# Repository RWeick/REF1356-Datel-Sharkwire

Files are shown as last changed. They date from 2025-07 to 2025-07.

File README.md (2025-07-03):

# REF1356-Datel-Sharkwire
Everything necessary to produce the N64 Sharkwire by Datel

This repository is the culmination of a joint effort between myself, [Jhynjhiruu](https://github.com/Jhynjhiruu), and [PPCASM](https://github.com/ppcasm). Without all of us, this wouldn't be here today. Shoutout to @WISE for being a great cheerleader throughout this endeavor. This PCB has been fully evaluated and is a complete replica of the original.

This repository now enables anyone with the necessary pcb assembly skills to fabricate an N64 Sharkwire. Some components must be harvested from an N64 Gameshark or Gameshark Pro. You are on your own to acquire the modem chipset, U11, and U13. They are COTS ICs, but seemingly hard to find. If you can find datasheets for U11 and U13, please share them with us!

Happy making!

PCB Thickness: 1.2 mm

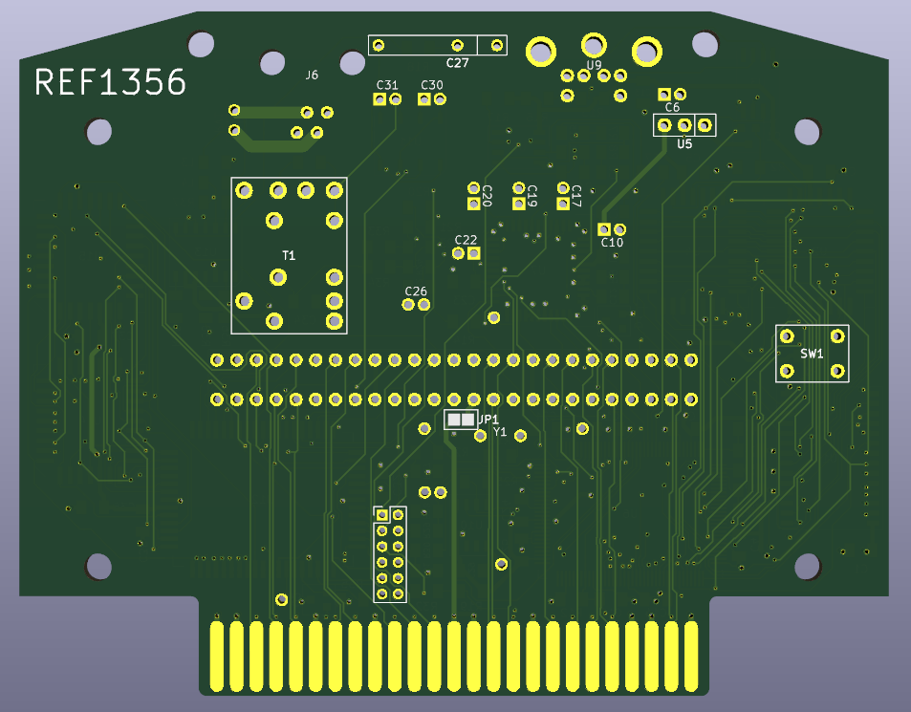
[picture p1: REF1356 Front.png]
Front side of the PCB


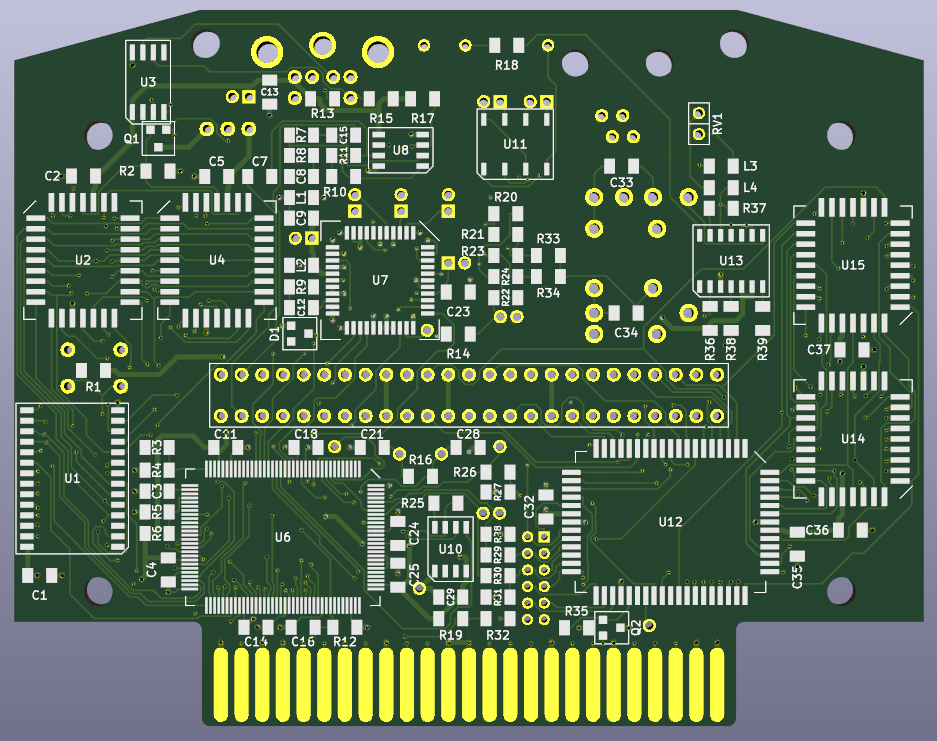
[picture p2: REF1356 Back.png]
Back side of the PCB


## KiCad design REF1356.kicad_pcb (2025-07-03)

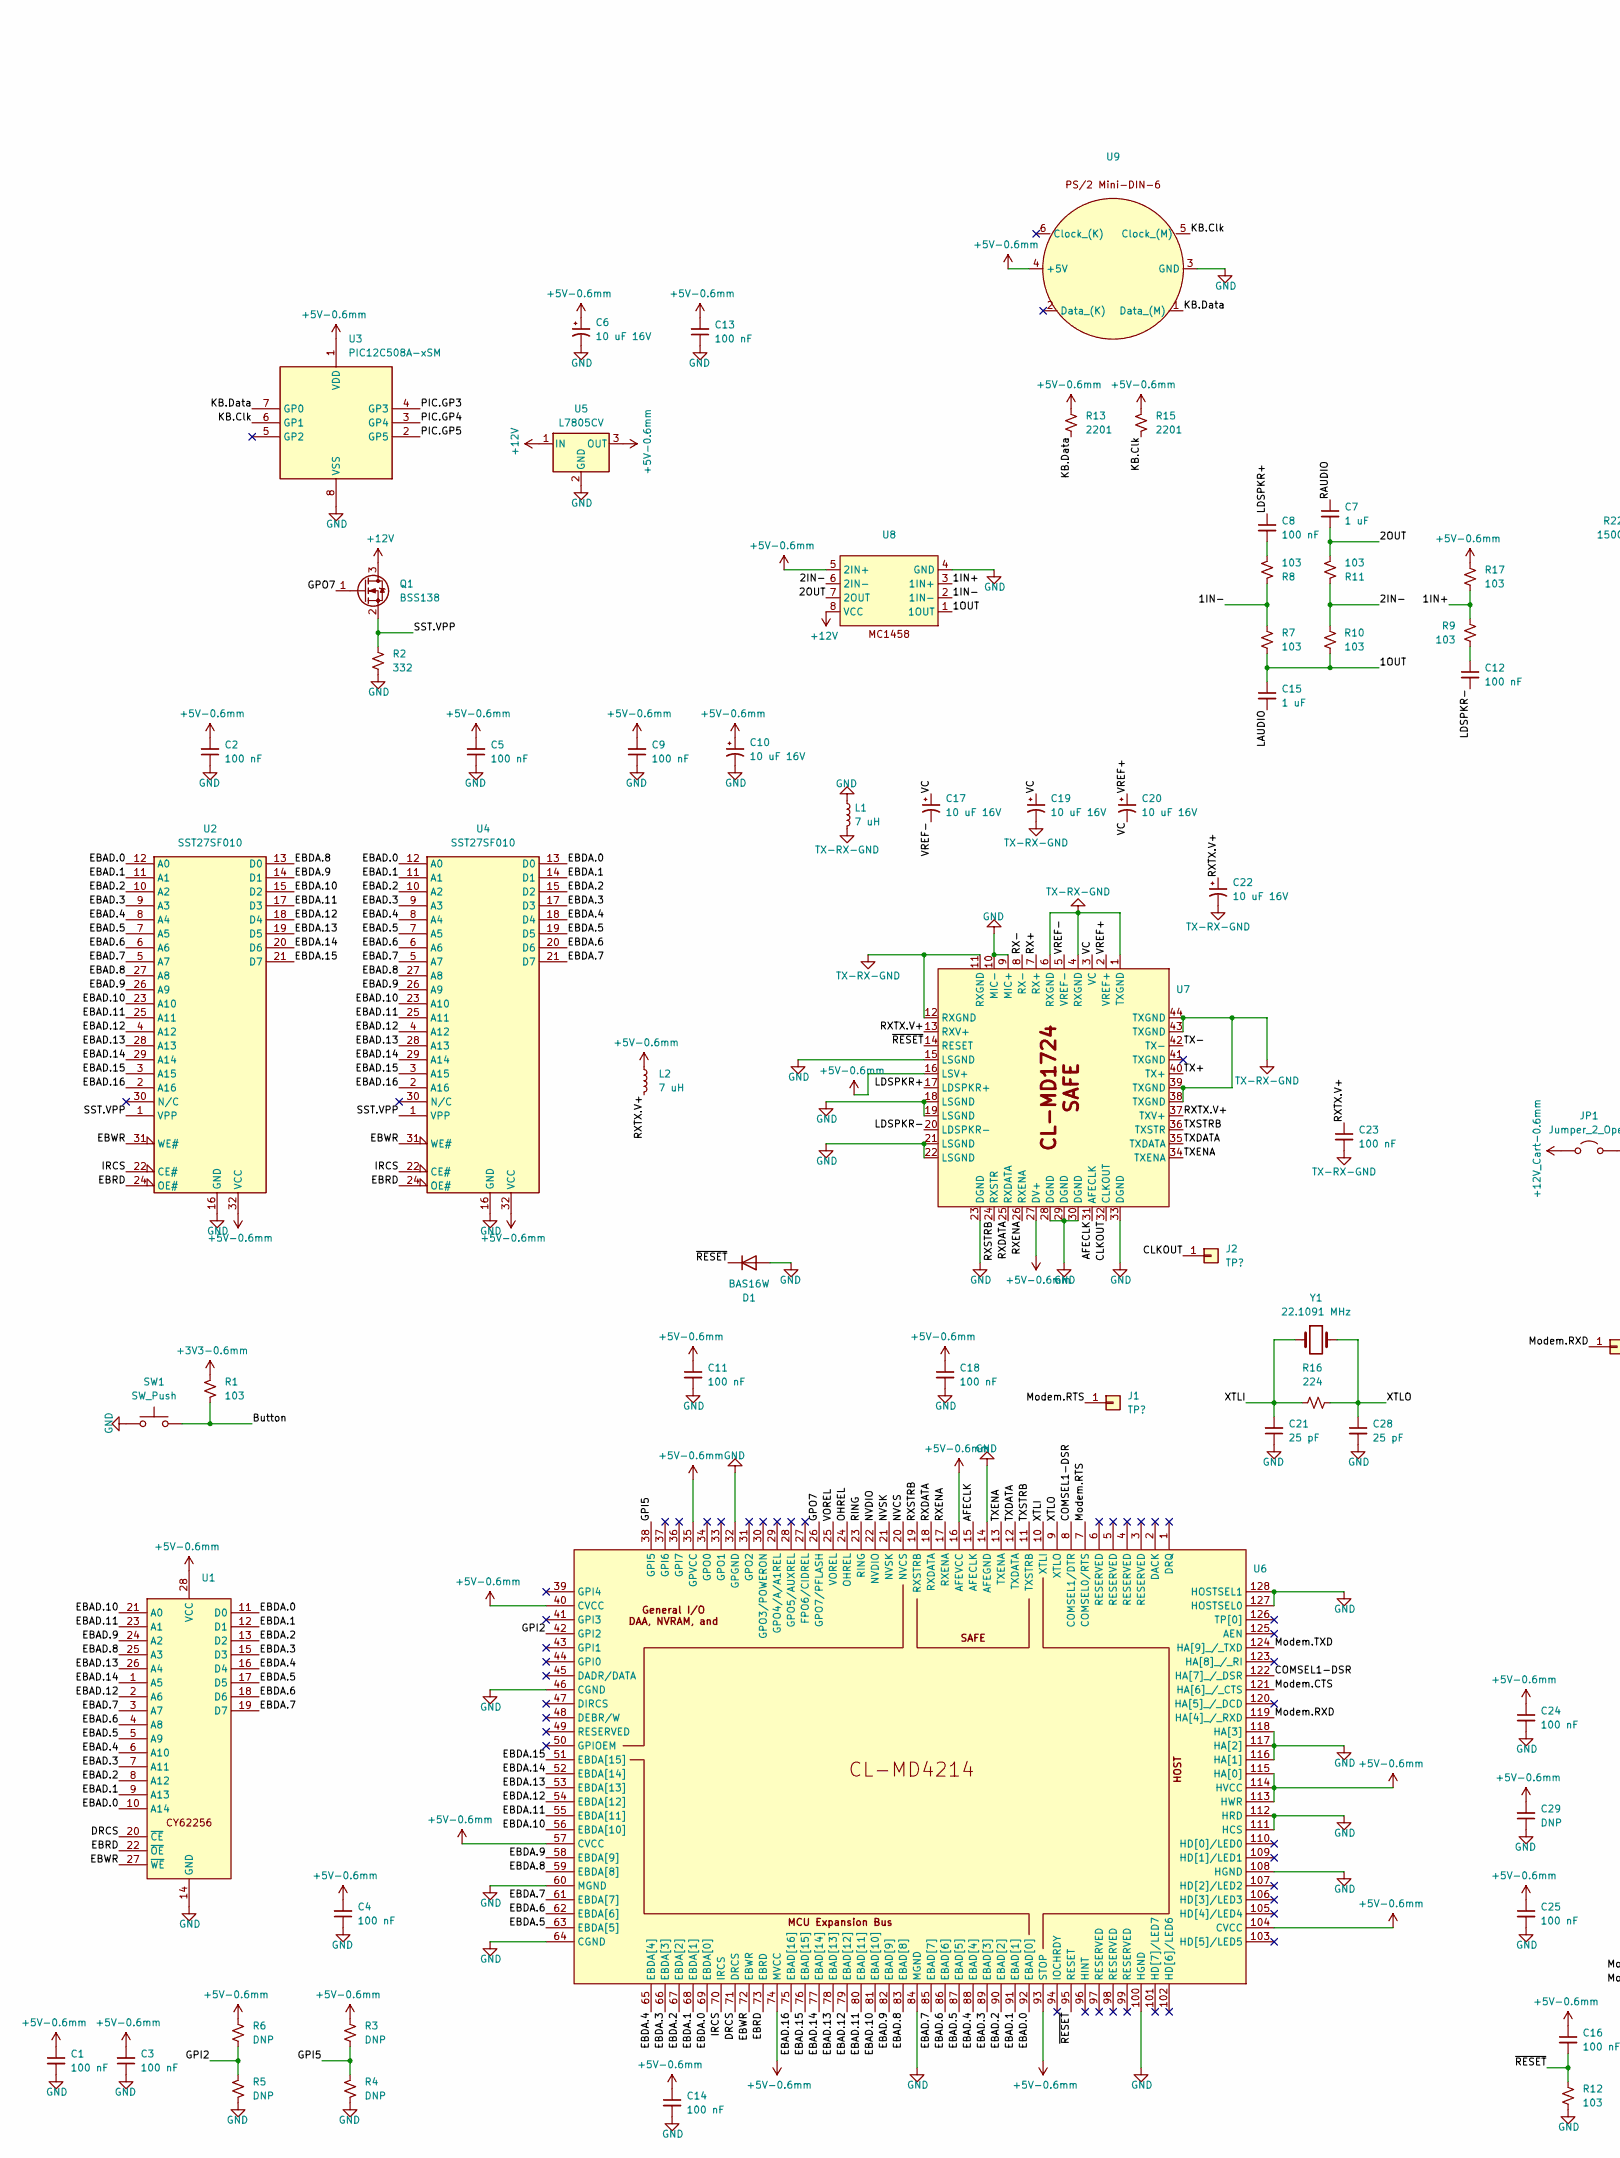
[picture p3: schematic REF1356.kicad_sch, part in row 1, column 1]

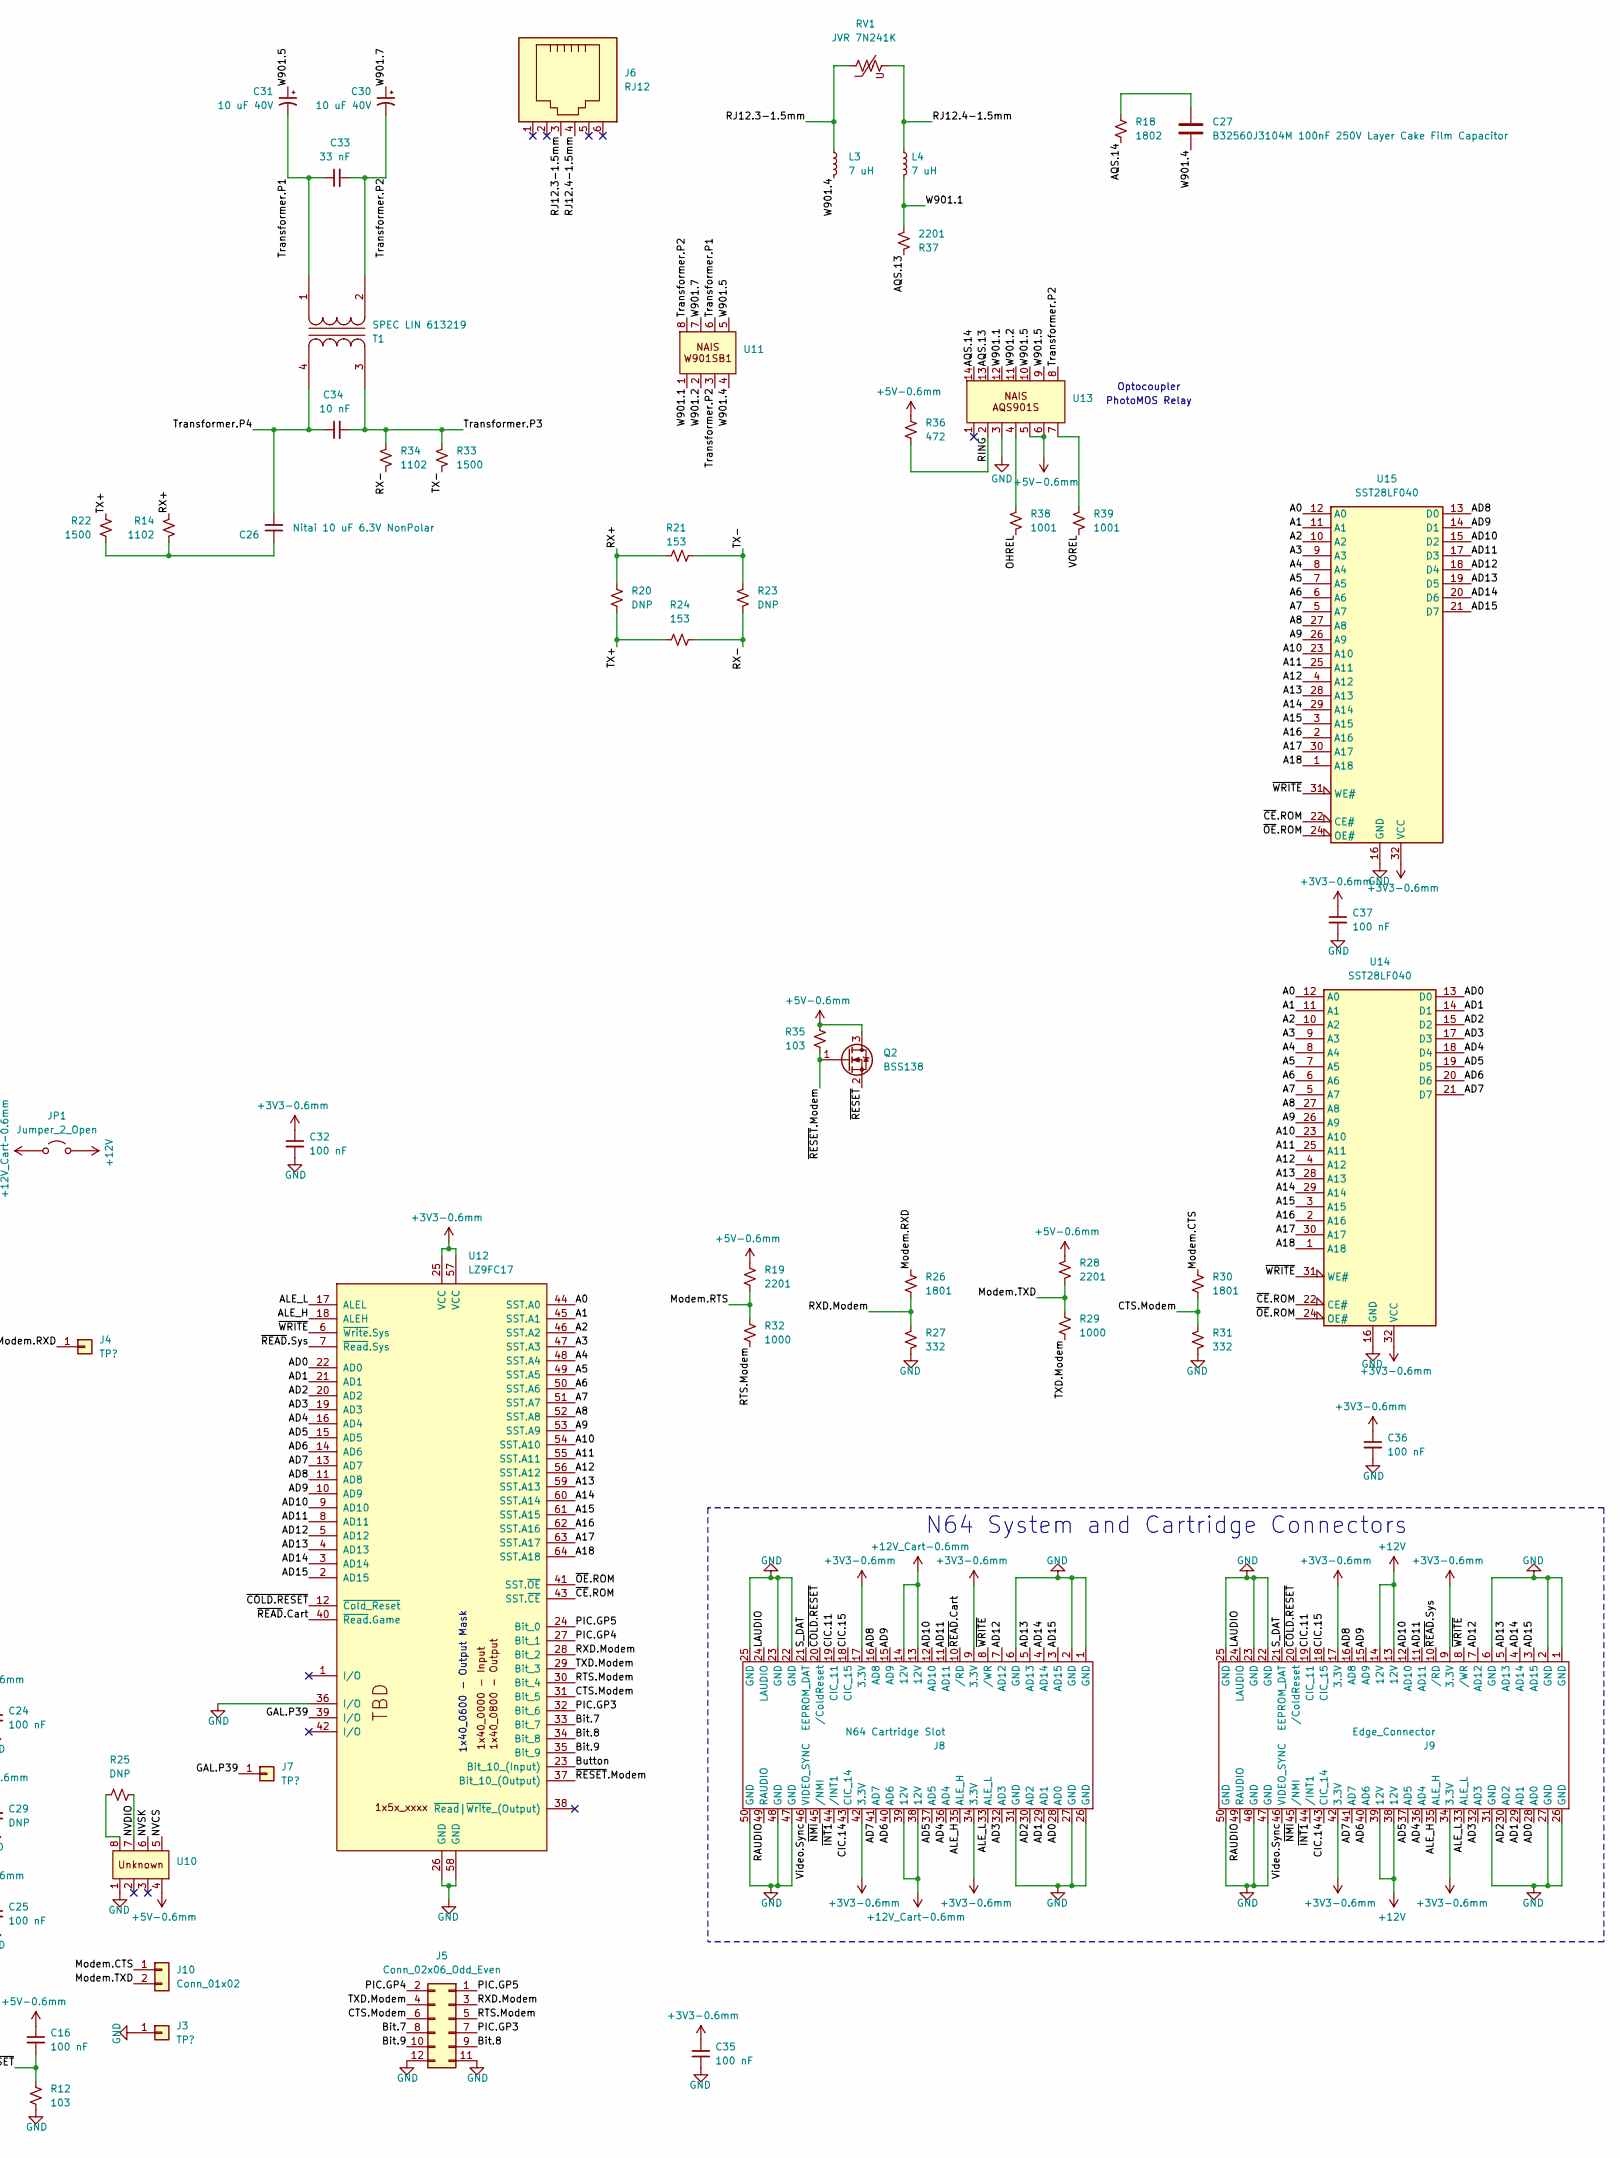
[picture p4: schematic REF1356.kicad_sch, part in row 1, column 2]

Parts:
C1, C2, C3, C4, C5, C8, C9, C11, C12, C13, C14, C16, C18, C23, C24, C25, C32, C35, C36, C37: 100 nF; SMD
C6, C10, C17, C19, C20, C22: 10 uF 16V; Polar Electrolytic
C7, C15: 1 uF; SMD
C21, C28: 25 pF; SMD
C26: Nitai 10 uF 6.3V NonPolar; Nonpolar Cap
C27: B32560J3104M 100nF 250V Layer Cake Film Capacitor; Layer Cake Film Cap
C29: DNP; SMD
C30, C31: 10 uF 40V; Polar Electrolytic
C33: 33 nF; SMD
C34: 10 nF; SMD
D1: BAS16W; Transistor
J1, J2, J3, J4, J7: TP?; Test Point
J5: Conn_02x06_Odd_Even; PinHeader_2x06_P2.00mm_Vertical
J6: RJ12; Modem Jack
J8: N64 Cartridge Slot; Cartridge Slot
J9: Edge_Connector; Edge Connector
J10: Conn_01x02; Nonpolar Cap
JP1: Jumper_2_Open; 12V Jumper
L1, L2, L3, L4: 7 uH; SMD
Q1, Q2: BSS138; Transistor
R1, R7, R8, R9, R10, R11, R12, R17, R35: 103; SMD
R2, R27, R31: 332; SMD
R3, R4, R5, R6, R20, R23, R25: DNP; SMD
R13, R15, R19, R28, R37: 2201; SMD
R14, R34: 1102; SMD
R16: 224; SMD
R18: 1802; SMD
R21, R24: 153; SMD
R22, R33: 1500; SMD
R26, R30: 1801; SMD
R29, R32: 1000; SMD
R36: 472; SMD
R38, R39: 1001; SMD
RV1: JVR 7N241K; Varistor
SW1: SW_Push; Button
T1: SPEC LIN 613219
U1: CY62256-70SNC
U2, U4: SST27SF010; PLCC32
U3: PIC12C508A-xSM; PIC 12C508A
U5: L7805CV
U6: CL-MD4214-22SC-A
U7: MD1724-11VC-D
U8, U10: MC1458
U9: PS_2 Keyboard Port
U11: W901SB1
U12: LZ9FC17
U13: AQS901S
U14, U15: SST28LF040; PLCC32
Y1: 22.1091 MHz; Crystal

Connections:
+3V3-0.6mm: C32.1, C35.2, C36.1, C37.1, J8.9 (3.3V), J8.17 (3.3V), J8.34 (3.3V), J8.42 (3.3V), J9.9 (3.3V), J9.17 (3.3V), J9.34 (3.3V), J9.42 (3.3V), R1.2, U12.25 (VCC), U12.57 (VCC), U14.32 (VCC), U15.32 (VCC)
+5V-0.6mm: C1.1, C2.2, C3.2, C4.2, C5.2, C6.1, C9.2, C10.1, C11.1, C13.2, C14.1, C16.1, C18.1, C24.1, C25.1, C29.2, L2.2, Q2.3 (D), R3.1, R6.1, R13.1, R15.2, R17.1, R19.1, R28.2, R35.2, R36.1, U1.28 (VCC), U2.32 (VCC), U3.1 (VDD), U4.32 (VCC), U5.3 (OUT), U6.16 (AFEVCC), U6.35 (GPVCC), U6.40 (CVCC), U6.57 (CVCC), U6.74 (MVCC), U6.93 (STOP), U6.104 (CVCC), U6.113 (HWR), U6.114 (HVCC), U6.115 (HA[0]), U7.16 (LSV+), U7.27 (DV+), U8.5 (2IN+), U9.4 (+5V), U10.4, U13.5, U13.6
+12V: J9.13 (12V), J9.14 (12V), J9.38 (12V), J9.39 (12V), JP1.2 (B), Q1.3 (D), U5.1 (IN), U8.8 (VCC)
+12V_Cart-0.6mm: J8.13 (12V), J8.14 (12V), J8.38 (12V), J8.39 (12V), JP1.1 (A)
/1IN+: R9.2, R17.2, U8.3 (1IN+)
/1IN-: R7.1, R8.1, U8.2 (1IN-)
/1OUT: C15.1, R7.2, R10.2, U8.1 (1OUT)
/2IN-: R10.1, R11.1, U8.6 (2IN-)
/2OUT: C7.2, R11.2, U8.7 (2OUT)
/A0: U12.44 (SST.A0), U14.12 (A0), U15.12 (A0)
/A1: U12.45 (SST.A1), U14.11 (A1), U15.11 (A1)
/A2: U12.46 (SST.A2), U14.10 (A2), U15.10 (A2)
/A3: U12.47 (SST.A3), U14.9 (A3), U15.9 (A3)
/A4: U12.48 (SST.A4), U14.8 (A4), U15.8 (A4)
/A5: U12.49 (SST.A5), U14.7 (A5), U15.7 (A5)
/A6: U12.50 (SST.A6), U14.6 (A6), U15.6 (A6)
/A7: U12.51 (SST.A7), U14.5 (A7), U15.5 (A7)
/A8: U12.52 (SST.A8), U14.27 (A8), U15.27 (A8)
/A9: U12.53 (SST.A9), U14.26 (A9), U15.26 (A9)
/A10: U12.54 (SST.A10), U14.23 (A10), U15.23 (A10)
/A11: U12.55 (SST.A11), U14.25 (A11), U15.25 (A11)
/A12: U12.56 (SST.A12), U14.4 (A12), U15.4 (A12)
/A13: U12.59 (SST.A13), U14.28 (A13), U15.28 (A13)
/A14: U12.60 (SST.A14), U14.29 (A14), U15.29 (A14)
/A15: U12.61 (SST.A15), U14.3 (A15), U15.3 (A15)
/A16: U12.62 (SST.A16), U14.2 (A16), U15.2 (A16)
/A17: U12.63 (SST.A17), U14.30 (A17), U15.30 (A17)
/A18: U12.64 (SST.A18), U14.1 (A18), U15.1 (A18)
/AD0: J8.28 (AD0), J9.28 (AD0), U12.22 (AD0), U14.13 (D0)
/AD1: J8.29 (AD1), J9.29 (AD1), U12.21 (AD1), U14.14 (D1)
/AD2: J8.30 (AD2), J9.30 (AD2), U12.20 (AD2), U14.15 (D2)
/AD3: J8.32 (AD3), J9.32 (AD3), U12.19 (AD3), U14.17 (D3)
/AD4: J8.36 (AD4), J9.36 (AD4), U12.16 (AD4), U14.18 (D4)
/AD5: J8.37 (AD5), J9.37 (AD5), U12.15 (AD5), U14.19 (D5)
/AD6: J8.40 (AD6), J9.40 (AD6), U12.14 (AD6), U14.20 (D6)
/AD7: J8.41 (AD7), J9.41 (AD7), U12.13 (AD7), U14.21 (D7)
/AD8: J8.16 (AD8), J9.16 (AD8), U12.11 (AD8), U15.13 (D0)
/AD9: J8.15 (AD9), J9.15 (AD9), U12.10 (AD9), U15.14 (D1)
/AD10: J8.12 (AD10), J9.12 (AD10), U12.9 (AD10), U15.15 (D2)
/AD11: J8.11 (AD11), J9.11 (AD11), U12.8 (AD11), U15.17 (D3)
/AD12: J8.7 (AD12), J9.7 (AD12), U12.5 (AD12), U15.18 (D4)
/AD13: J8.5 (AD13), J9.5 (AD13), U12.4 (AD13), U15.19 (D5)
/AD14: J8.4 (AD14), J9.4 (AD14), U12.3 (AD14), U15.20 (D6)
/AD15: J8.3 (AD15), J9.3 (AD15), U12.2 (AD15), U15.21 (D7)
/AFECLK: U6.15 (AFECLK), U7.31 (AFECLK)
/ALE_H: J8.35 (ALE_H), J9.35 (ALE_H), U12.18 (ALEH)
/ALE_L: J8.33 (ALE_L), J9.33 (ALE_L), U12.17 (ALEL)
/AQS.13: R37.1, U13.13
/AQS.14: R18.2, U13.14
/Bit.8: J5.9, U12.34 (Bit_8)
/Bit.9: J5.10, U12.35 (Bit_9)
/Button: R1.1, SW1.2, U12.23 (Bit_10_(Input))
/CIC.11: J8.19 (CIC_11), J9.19 (CIC_11)
/CIC.14: J8.43 (CIC_14), J9.43 (CIC_14)
/CIC.15: J8.18 (CIC_15), J9.18 (CIC_15)
/CLKOUT: J2.1, U7.32 (CLKOUT)
/COMSEL1-DSR: U6.8 (COMSEL1/DTR), U6.122 (HA[7]_/_DSR)
/CTS.Modem: J5.6, R30.2, R31.2, U12.31 (Bit_5)
/DRCS: U1.20 (~CE), U6.71 (DRCS)
/EBAD.0: U1.10 (A14), U2.12 (A0), U4.12 (A0), U6.92 (EBAD[0])
/EBAD.1: U1.9 (A13), U2.11 (A1), U4.11 (A1), U6.91 (EBAD[1])
/EBAD.2: U1.8 (A12), U2.10 (A2), U4.10 (A2), U6.90 (EBAD[2])
/EBAD.3: U1.7 (A11), U2.9 (A3), U4.9 (A3), U6.89 (EBAD[3])
/EBAD.4: U1.6 (A10), U2.8 (A4), U4.8 (A4), U6.88 (EBAD[4])
/EBAD.5: U1.5 (A9), U2.7 (A5), U4.7 (A5), U6.87 (EBAD[5])
/EBAD.6: U1.4 (A8), U2.6 (A6), U4.6 (A6), U6.86 (EBAD[6])
/EBAD.7: U1.3 (A7), U2.5 (A7), U4.5 (A7), U6.85 (EBAD[7])
/EBAD.8: U1.25 (A3), U2.27 (A8), U4.27 (A8), U6.83 (EBAD[8])
/EBAD.9: U1.24 (A2), U2.26 (A9), U4.26 (A9), U6.82 (EBAD[9])
/EBAD.10: U1.21 (A0), U2.23 (A10), U4.23 (A10), U6.81 (EBAD[10])
/EBAD.11: U1.23 (A1), U2.25 (A11), U4.25 (A11), U6.80 (EBAD[11])
/EBAD.12: U1.2 (A6), U2.4 (A12), U4.4 (A12), U6.79 (EBAD[12])
/EBAD.13: U1.26 (A4), U2.28 (A13), U4.28 (A13), U6.78 (EBAD[13])
/EBAD.14: U1.1 (A5), U2.29 (A14), U4.29 (A14), U6.77 (EBAD[14])
/EBAD.15: U2.3 (A15), U4.3 (A15), U6.76 (EBAD[15])
/EBAD.16: U2.2 (A16), U4.2 (A16), U6.75 (EBAD[16])
/EBDA.0: U1.11 (D0), U4.13 (D0), U6.69 (EBDA[0])
/EBDA.1: U1.12 (D1), U4.14 (D1), U6.68 (EBDA[1])
/EBDA.2: U1.13 (D2), U4.15 (D2), U6.67 (EBDA[2])
/EBDA.3: U1.15 (D3), U4.17 (D3), U6.66 (EBDA[3])
/EBDA.4: U1.16 (D4), U4.18 (D4), U6.65 (EBDA[4])
/EBDA.5: U1.17 (D5), U4.19 (D5), U6.63 (EBDA[5])
/EBDA.6: U1.18 (D6), U4.20 (D6), U6.62 (EBDA[6])
/EBDA.7: U1.19 (D7), U4.21 (D7), U6.61 (EBDA[7])
/EBDA.8: U2.13 (D0), U6.59 (EBDA[8])
/EBDA.9: U2.14 (D1), U6.58 (EBDA[9])
/EBDA.10: U2.15 (D2), U6.56 (EBDA[10])
/EBDA.11: U2.17 (D3), U6.55 (EBDA[11])
/EBDA.12: U2.18 (D4), U6.54 (EBDA[12])
/EBDA.13: U2.19 (D5), U6.53 (EBDA[13])
/EBDA.14: U2.20 (D6), U6.52 (EBDA[14])
/EBDA.15: U2.21 (D7), U6.51 (EBDA[15])
/EBRD: U1.22 (~OE), U2.24 (OE#), U4.24 (OE#), U6.73 (EBRD)
/EBWR: U1.27 (~WE), U2.31 (WE#), U4.31 (WE#), U6.72 (EBWR)
/GAL.P33: J5.8, U12.33 (I/O)
/GAL.P39: J7.1, U12.39 (I/O)
/GPI2: R5.2, R6.2, U6.42 (GPI2)
/GPI5: R3.2, R4.2, U6.38 (GPI5)
/GPO7: Q1.1 (G), U6.26 (GPO7/PFLASH)
/IRCS: U2.22 (CE#), U4.22 (CE#), U6.70 (IRCS)
/KB.Clk: R15.1, U3.6 (GP1), U9.5 (Clock_(M))
/KB.Data: R13.2, U3.7 (GP0), U9.1 (Data_(M))
/LAUDIO: C15.2, J8.24 (LAUDIO), J9.24 (LAUDIO)
/LDSPKR+: C8.1, U7.17 (LDSPKR+)
/LDSPKR-: C12.2, U7.20 (LDSPKR-)
/Modem.CTS: J10.1, R30.1, U6.121 (HA[6]_/_CTS)
/Modem.RTS: J1.1, R19.2, R32.1, U6.7 (COMSEL0/RTS)
/Modem.RXD: J4.1, R26.1, U6.119 (HA[4]_/_RXD)
/Modem.TXD: J10.2, R28.1, R29.1, U6.124 (HA[9]_/_TXD)
/NVCS: U6.20 (NVCS), U10.5
/NVDIO: R25.2, U6.22 (NVDIO), U10.7
/NVSK: U6.21 (NVSK), U10.6
/OHREL: R38.1, U6.24 (OHREL)
/PIC.GP3: J5.7, U3.4 (GP3), U12.32 (Bit_6)
/PIC.GP4: J5.2, U3.3 (GP4), U12.27 (Bit_1)
/PIC.GP5: J5.1, U3.2 (GP5), U12.24 (Bit_0)
/RAUDIO: C7.1, J8.49 (RAUDIO), J9.49 (RAUDIO)
/RING: R36.2, U6.23 (RING), U13.2
/RJ12.3-1.5mm: J6.3, L3.2, RV1.1
/RJ12.4-1.5mm: J6.4, L4.1, RV1.2
/RTS.Modem: J5.5, R32.2, U12.30 (Bit_4)
/RX+: R14.1, R20.1, R21.1, U7.7 (RX+)
/RX-: R23.1, R24.2, R34.1, U7.8 (RX-)
/RXD.Modem: J5.3, R26.2, R27.2, U12.28 (Bit_2)
/RXDATA: U6.18 (RXDATA), U7.25 (RXDATA)
/RXENA: U6.17 (RXENA), U7.26 (RXENA)
/RXSTRB: U6.19 (RXSTRB), U7.24 (RXSTR)
/RXTX.V+: C22.1, C23.1, L2.1, U7.13 (RXV+), U7.37 (TXV+)
/SST.VPP: Q1.2 (S), R2.1, U2.1 (VPP), U4.1 (VPP)
/S_DAT: J8.21 (EEPROM_DAT), J9.21 (EEPROM_DAT)
/TX+: R20.2, R22.2, R24.1, U7.40 (TX+)
/TX-: R21.2, R23.2, R33.1, U7.42 (TX-)
/TXD.Modem: J5.4, R29.2, U12.29 (Bit_3)
/TXDATA: U6.12 (TXDATA), U7.35 (TXDATA)
/TXENA: U6.13 (TXENA), U7.34 (TXENA)
/TXSTRB: U6.11 (TXSTRB), U7.36 (TXSTR)
/Transformer.P1: C31.2, C33.1, T1.1 (AA), U11.6
/Transformer.P2: C30.2, C33.2, T1.2 (AB), U11.3, U11.8, U13.8
/Transformer.P3: C34.2, R33.2, R34.2, T1.3 (SA)
/Transformer.P4: C26.2, C34.1, T1.4 (SB)
/VC: C17.1, C19.1, C20.2, U7.3 (VC)
/VOREL: R39.1, U6.25 (VOREL)
/VREF+: C20.1, U7.2 (VREF+)
/VREF-: C17.2, U7.5 (VREF-)
/Video.Sync: J8.46 (VIDEO_SYNC), J9.46 (VIDEO_SYNC)
/W901.1: L4.2, R37.2, U11.1, U13.12
/W901.2: U11.2, U13.11
/W901.4: C27.2, L3.1, U11.4
/W901.5: C31.1, U11.5, U13.9, U13.10
/W901.7: C30.1, U11.7
/XTLI: C21.2, R16.1, U6.10 (XTLI), Y1.1
/XTLO: C28.1, R16.2, U6.9 (XTLO), Y1.2
/~CE.ROM: U12.43 (SST.~CE), U14.22 (CE#), U15.22 (CE#)
/~COLD.RESET: J8.20 (/ColdReset), J9.20 (/ColdReset), U12.12 (~Cold_Reset)
/~INT1: J8.44 (/INT1), J9.44 (/INT1)
/~NMI: J8.45 (/NMI), J9.45 (/NMI)
/~OE.ROM: U12.41 (SST.~OE), U14.24 (OE#), U15.24 (OE#)
/~READ.Cart: J8.10 (/RD), U12.40 (~Read.Game)
/~READ.Sys: J9.10 (/RD), U12.7 (~Read.Sys)
/~RESET: C16.2, D1.3 (K), Q2.2 (S), R12.1, U6.95 (RESET), U7.14 (RESET)
/~RESET.Modem: Q2.1 (G), R35.1, U12.37 (Bit_10_(Output))
/~WRITE: J8.8 (/WR), J9.8 (/WR), U12.6 (~Write.Sys), U14.31 (WE#), U15.31 (WE#)
GND: C1.2, C2.1, C3.1, C4.1, C5.1, C6.2, C9.1, C10.2, C11.2, C13.1, C14.2, C18.2, C21.1, C24.2, C25.2, C28.2, C29.1, C32.2, C35.1, C36.2, C37.2, D1.1 (A), J3.1, J5.11, J5.12, J8.1 (GND), J8.2 (GND), J8.6 (GND), J8.22 (GND), J8.23 (GND), J8.25 (GND), J8.26 (GND), J8.27 (GND), J8.31 (GND), J8.47 (GND), J8.48 (GND), J8.50 (GND), J9.1 (GND), J9.2 (GND), J9.6 (GND), J9.22 (GND), J9.23 (GND), J9.25 (GND), J9.26 (GND), J9.27 (GND), J9.31 (GND), J9.47 (GND), J9.48 (GND), J9.50 (GND), L1.1, R2.2, R4.1, R5.1, R12.2, R27.1, R31.1, SW1.1, U1.14 (GND), U2.16 (GND), U3.8 (VSS), U4.16 (GND), U5.2 (GND), U6.14 (AFEGND), U6.32 (GPGND), U6.46 (CGND), U6.60 (MGND), U6.64 (CGND), U6.84 (MGND), U6.100 (HGND), U6.108 (HGND), U6.111 (HCS), U6.112 (HRD), U6.116 (HA[1]), U6.117 (HA[2]), U6.118 (HA[3]), U6.127 (HOSTSEL0), U6.128 (HOSTSEL1), U7.9 (MIC+), U7.10 (MIC-), U7.15 (LSGND), U7.18 (LSGND), U7.19 (LSGND), U7.21 (LSGND), U7.22 (LSGND), U7.23 (DGND), U7.28 (DGND), U7.29 (DGND), U7.30 (DGND), U7.33 (DGND), U8.4 (GND), U9.3 (GND), U10.1, U12.26 (GND), U12.36 (I/O), U12.58 (GND), U13.3, U14.16 (GND), U15.16 (GND)
unnamed: C8.2, R8.2
unnamed: C12.1, R9.1
unnamed: C26.1, R14.2, R22.1
unnamed: C27.1, R18.1
unnamed: R25.1, U10.8
unnamed: R38.2, U13.4
unnamed: R39.2, U13.7
TX-RX-GND: C19.2, C22.2, C23.2, L1.2, U7.1 (TXGND), U7.4 (RXGND), U7.6 (RXGND), U7.11 (RXGND), U7.12 (RXGND), U7.38 (TXGND), U7.39 (TXGND), U7.43 (TXGND), U7.44 (TXGND)

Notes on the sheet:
Optocoupler
PhotoMOS Relay
1x40_0600 - Output Mask
N64 System and Cartridge Connectors

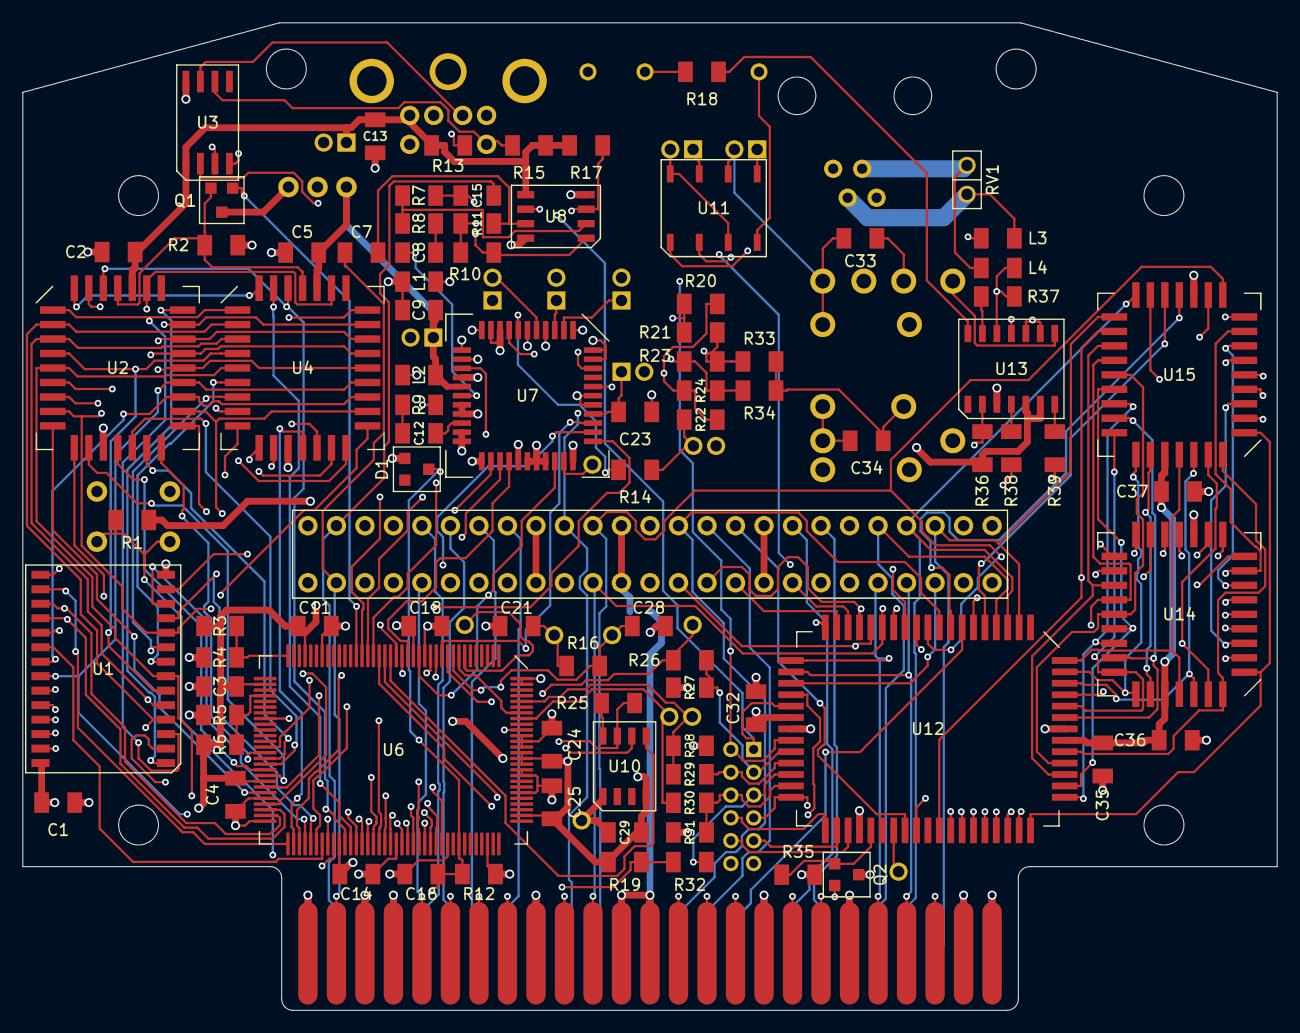
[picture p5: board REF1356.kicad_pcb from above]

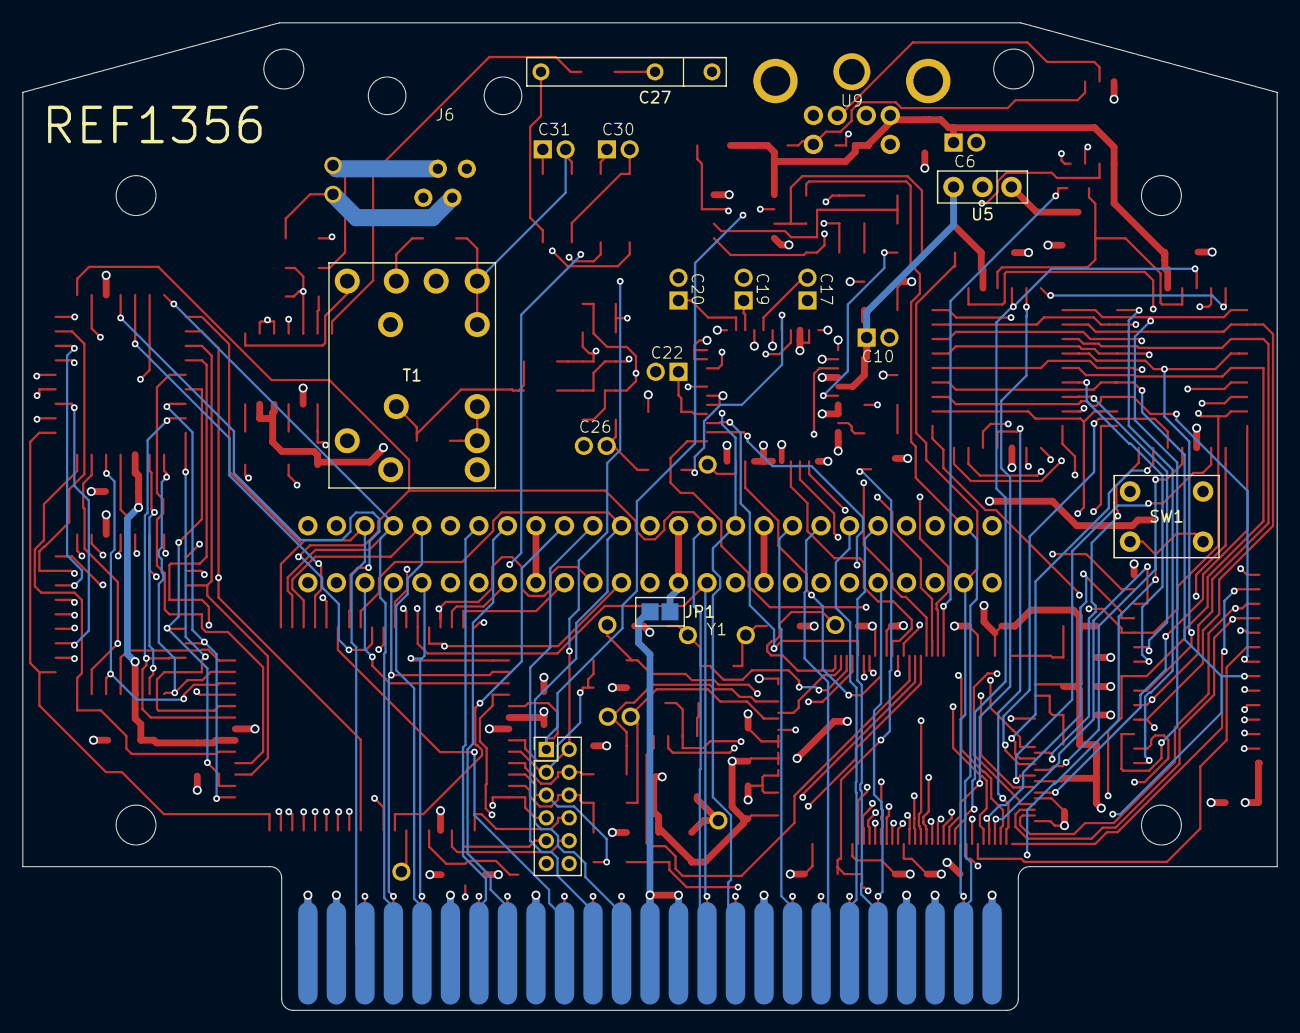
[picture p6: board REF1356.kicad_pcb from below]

Board: 4 copper layers, 110.0 x 86.6 mm, 113 parts (3 on the bottom side), 171 nets.
